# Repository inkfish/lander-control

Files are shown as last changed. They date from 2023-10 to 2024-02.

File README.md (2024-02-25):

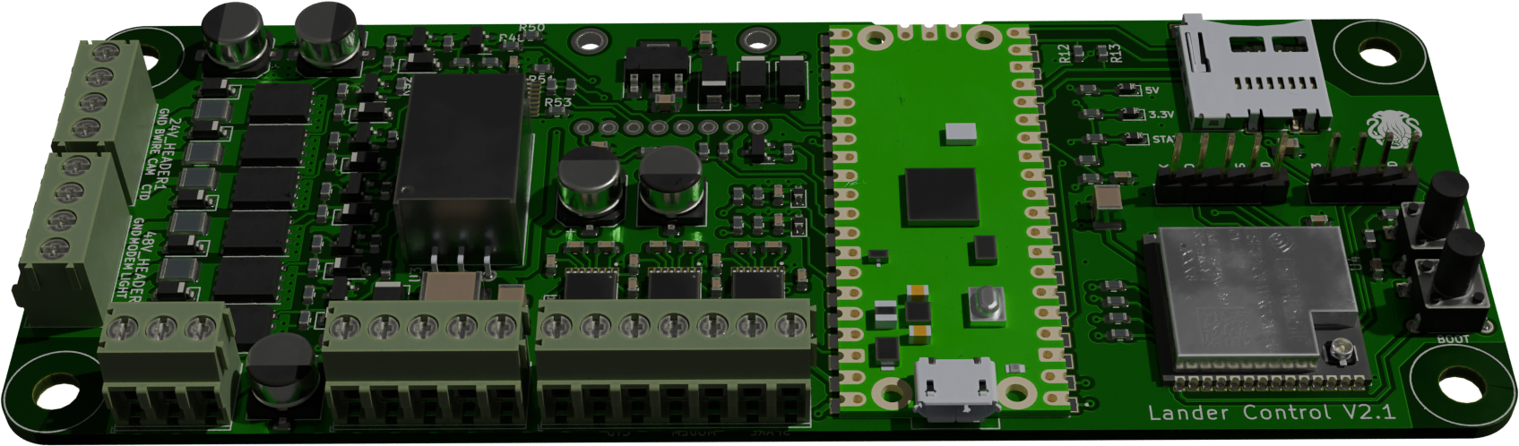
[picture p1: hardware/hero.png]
Hero image


# Lander Control Board for the Inkfish Hadal Exploration System

This repository contains firmware source code and hardware design files for the Lander Control Board used by the Inkfish Hadal Exploration System.

The Lander Control Board is responsible for switching power to the lander's peripherals, including a CTD, acoustic modem, camera, and lights. The board logs CTD data and responds to commands received via the acoustic modem.

The Lander Control Board is a motherboard for a [Raspberry Pi Pico][Pico]. A secondary microcontroller, an [Espressif ESP32-C6-WROOM-1U][ESP32], adds Wi-Fi capabilities. Timekeeping is assisted by an external GPS receiver along with an [Adafruit DS3231 Precision Real-Time Clock Breakout][RTC].

The firmware is written in [CircuitPython][] in order to be easily modifiable in the field and for compatibility with future microcontrollers. Data will be logged in the [MCAP][] file format.

[CircuitPython]: https://circuitpython.org/
[ESP32]: https://www.espressif.com/en/products/socs/esp32-c6
[MCAP]: https://mcap.dev/
[Pico]: https://www.raspberrypi.com/products/raspberry-pi-pico/
[RTC]: https://www.adafruit.com/product/3013

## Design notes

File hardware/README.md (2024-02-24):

# Hardware Design for Lander Control Board

This directory contains [KiCad][] schematic and PCB files for the Lander Control Board.

Designed by [Boston Precision Motion][] for Inkfish.

[Boston Precision Motion]: https://bostonprecisionmotion.com/
[KiCad]: https://www.kicad.org

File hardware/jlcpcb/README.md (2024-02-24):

This directory contains files to assist in preparing the design files for production at [JLCPCB][] using the [JLCPCB Tools][kicad-jlcpcb-tools] plugin.

Production files (Gerber files, BOMs, etc.) will also be attached on the project's Releases pages.

[JLCPCB]: https://jlcpcb.com/
[kicad-jlcpcb-tools]: https://github.com/Bouni/kicad-jlcpcb-tools

## Loading the project database

The KiCad plugin stores a mapping of footprints to LCSC part numbers (the same part numbers used by JLCPCB) in a SQLite database. The database can be created from the `project.db.sql` file, and vice versa:

    $ rm -f project.db && sqlite3 project.db < project.db.sql
    $ sqlite3 project.db .dump > project.db.sql

## Loading the rotations

JLCPCB parts usually need to be rotated by some amount to get the correct placement during assembly. The mapping of footprint to rotation is provided in `rotations.csv`.

To import, open the KiCad plugin's interface (Tools > External Plugins > JLCPCB Tools), click "Rotations" on the toolbar, then click the "Import" button and select the `rotations.csv` file.

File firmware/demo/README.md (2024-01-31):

This directory contains simple scripts for testing functionality of individual board components.

To load a script, attach the Raspberry Pi Pico to a PC using a USB cable. The volume "CIRCUITPY" should appear. Copy the demo script to this drive.

> [!IMPORTANT]  
> An issue with the userspace FAT driver on macOS prevents copying to the CIRCUITPY volume ([issue #8449](https://github.com/adafruit/circuitpython/issues/8449)). The script `./utils/remount-circuitpy.sh` works around this bug.

Open a serial connection to the Pico and press Ctrl-C to break into the REPL. Enter `import scriptname` (omitting the `.py` extension) to run the code.

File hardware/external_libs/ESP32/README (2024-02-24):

A 3D model of this component can be obtained from

https://grabcad.com/library/esp32-c6-wroom-1u-1

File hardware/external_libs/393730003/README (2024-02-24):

Please obtain this library from Ultra Librarian:

https://app.ultralibrarian.com/details/8e2498f5-ea90-11eb-9033-0a34d6323d74/Molex-Connector-Corporation/393730003

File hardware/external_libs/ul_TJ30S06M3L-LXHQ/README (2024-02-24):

Please obtain this library from Ultra Librarian:

https://app.ultralibrarian.com/details/ae27674b-4302-11eb-9033-0a34d6323d74/Toshiba-Electronic-Devices-Storage-Corp-/TJ30S06M3L-LXHQ

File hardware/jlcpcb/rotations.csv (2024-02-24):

Footprint pattern | Correction
^C_0603_1608Metric$ | 0
^C_0805_2012Metric$ | 0
^C_1210_3225Metric$ | 0
^C_2220_5650Metric$ | 0
^CP_Elec_6\.3x4\.9$ | 0
^D_0603_1608Metric$ | 0
^D_SMA$ | 0
^D_SOD-123$ | 0
^GCT_MEM2051-00-195-00-A$ | 90
^MODULE_SC0915$ | 270
^PinHeader_1x04_P2\.54mm_Vertical$ | 90
^PinHeader_1x05_P2\.54mm_Vertical$ | 90
^PowerPAK_SO-8_Single$ | 0
^R_0603_1608Metric$ | 0
^R_1206_3216Metric$ | 0
^R_1210_3225Metric$ | 0
^SI7489DP-T1-E3$ | 270
^SOP65P640X110-16N$ | 270
^SOP65P640X120-16N$ | 270
^SOT-223-3_TabPin2$ | 180
^SOT-23$ | 180

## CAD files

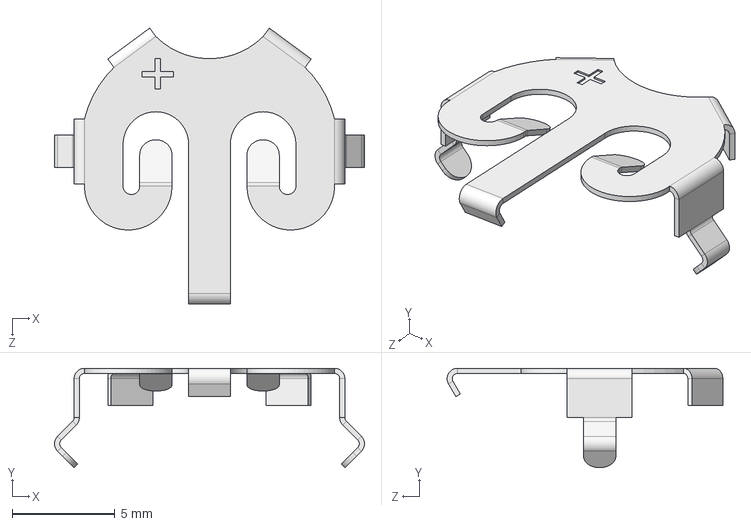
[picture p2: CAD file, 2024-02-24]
hardware/external_libs/CellHolder/2895.step
15.1 x 4.85 x 13.5 mm

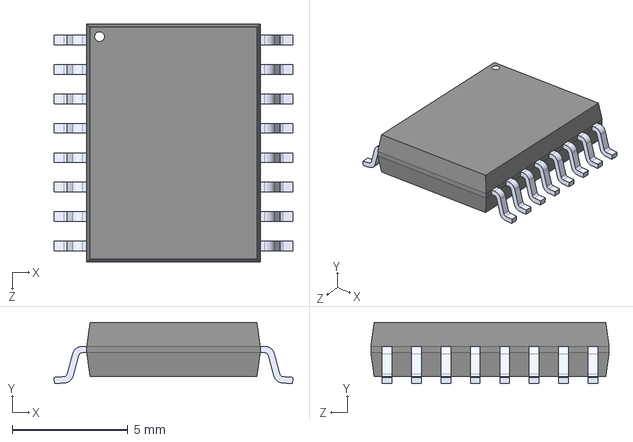
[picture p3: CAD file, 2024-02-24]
hardware/external_libs/DS3231S/DS3231S.step
10.3 x 2.65 x 10.3 mm

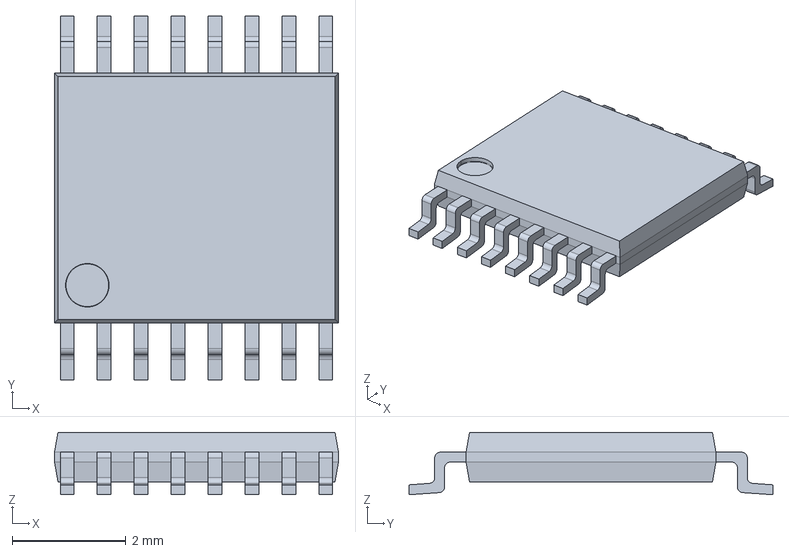
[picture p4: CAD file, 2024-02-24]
hardware/external_libs/GPIOEXPANDER/PCA9500PW_118.step
5.00 x 6.41 x 1.10 mm

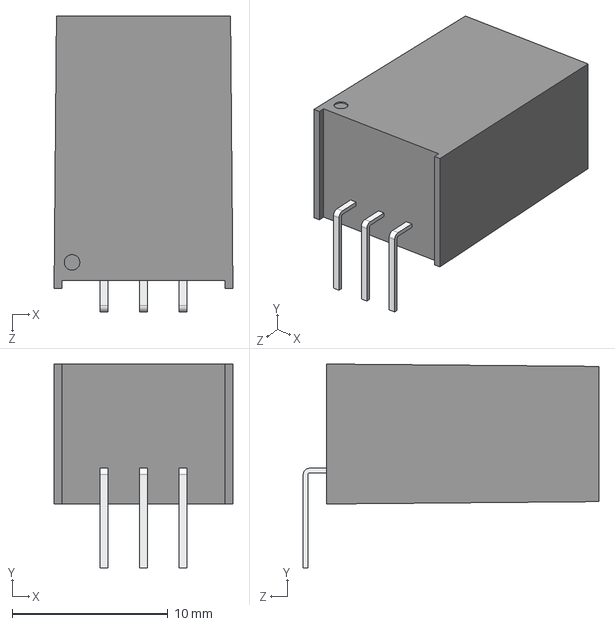
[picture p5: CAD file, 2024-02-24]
hardware/external_libs/P7805-500R/P7805-500R.step
11.5 x 13.1 x 19.0 mm

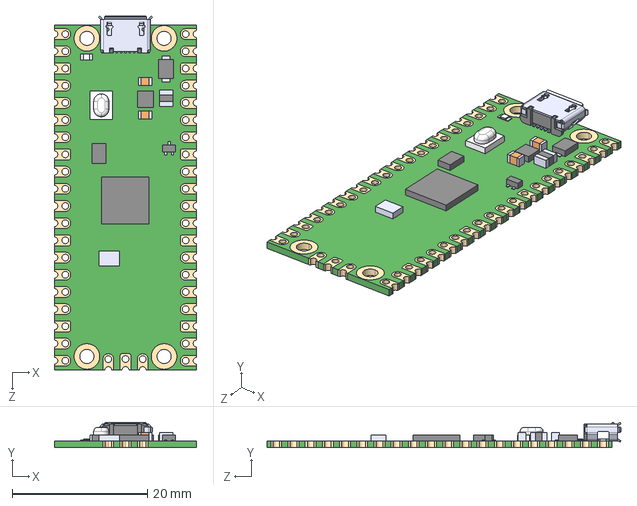
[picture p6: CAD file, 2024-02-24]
hardware/external_libs/PICO/SC0915.step
21.0 x 3.73 x 52.3 mm

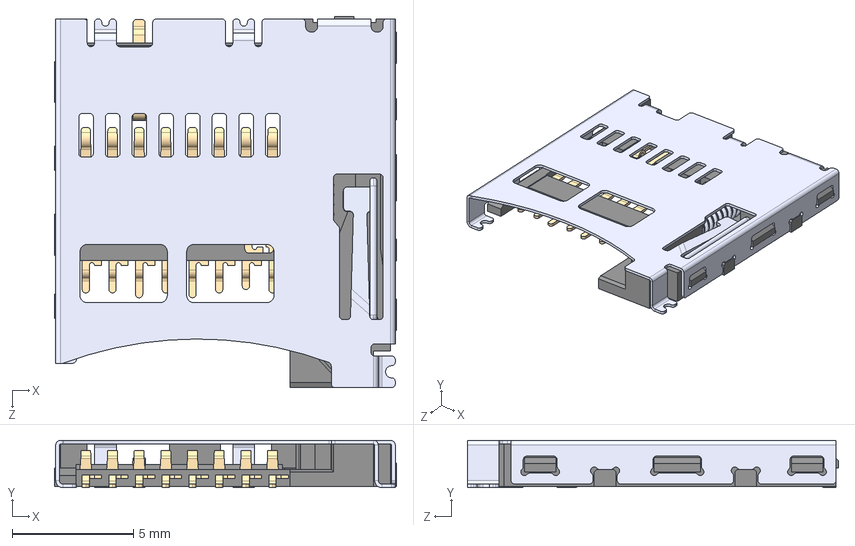
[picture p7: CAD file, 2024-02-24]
hardware/external_libs/sdcard/MEM2051-00-195-00-A.step
14.1 x 1.95 x 15.3 mm

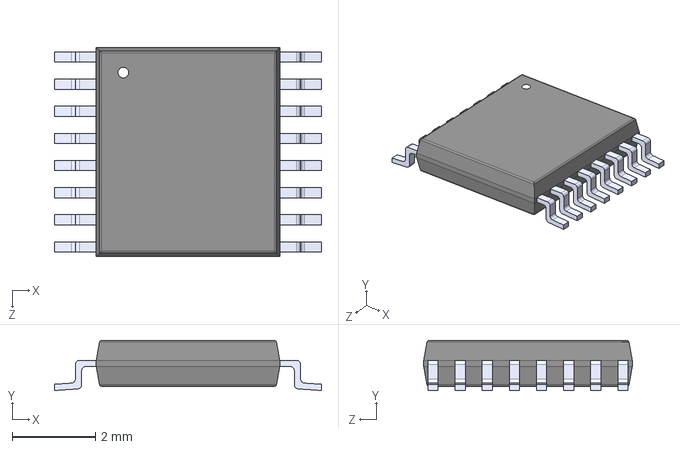
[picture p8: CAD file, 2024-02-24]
hardware/external_libs/SN65C3221EPWR/SN65C3221EPWR.step
6.40 x 1.20 x 5.00 mm

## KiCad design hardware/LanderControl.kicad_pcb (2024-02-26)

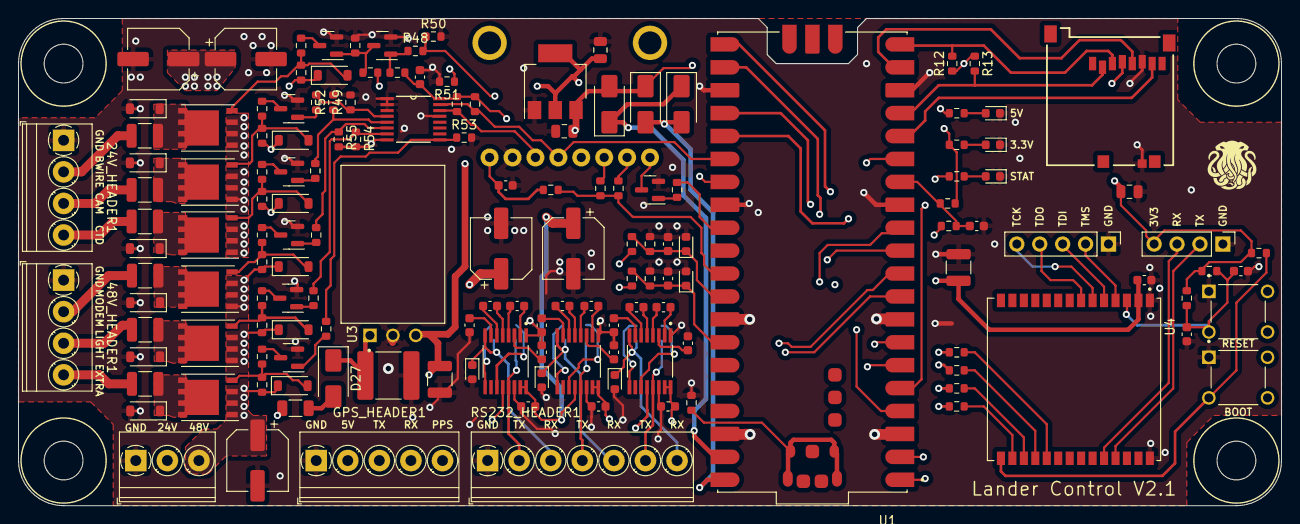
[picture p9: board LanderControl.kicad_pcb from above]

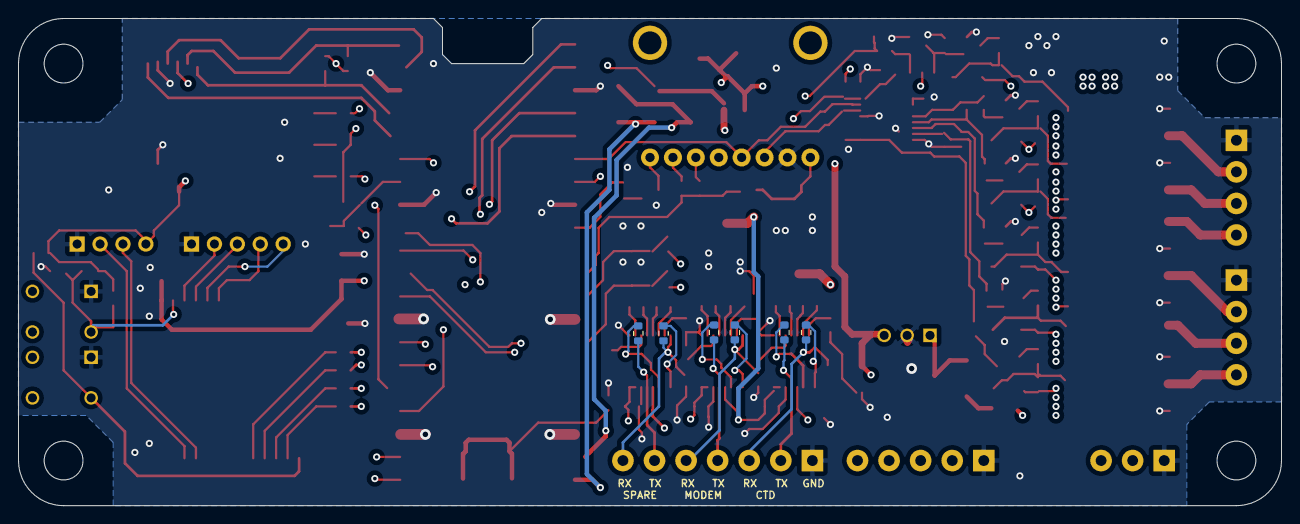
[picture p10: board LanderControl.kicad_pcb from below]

Board: 4 copper layers, 140.0 x 54.0 mm, 157 parts (6 on the bottom side), 115 nets.

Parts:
24V_HEADER1, 48V_HEADER1: Conn_01x04; TerminalBlock_Phoenix_PT-1,5-4-3.5-H_1x04_P3.50mm_Horizontal
C1, C2, C30: 1nF; C_0603_1608Metric
C3, C5, C12, C13, C14, C15, C16, C17, C18, C19, C20, C21, C22, C23, C24, C25, C26: 100nF; C_0603_1608Metric
C4, C11, C27: 1uF; C_0603_1608Metric
C6, C8: 22uF; C_1210_3225Metric
C7: 10uF; C_2220_5650Metric
C9, C10: 1uF; C_0805_2012Metric
C28, C29, C35, C37: >25V>25uF; CP_Elec_6.3x4.9
C31: 4.7uF; C_0805_2012Metric
C36: >50V>25uF; CP_Elec_6.3x4.9
D1, D2, D8, D10, D12: D_Zener; D_0603_1608Metric
D3, D25, D26, D27: B120-E3; D_SMA
D4, D5, D6: LED; D_0603_1608Metric
D13, D14, D17, D18, D21, D22: D_Zener; D_SOD-123
D15, D16, D19, D23, D24: 1N4148W; D_SOD-123
D20: SS210LW; D_SOD-123
DNP1, DNP2, DNP3, DNP4, DNP5, DNP6: 0; R_0603_1608Metric
DNP_R1: 0; R_0603_1608Metric
GPS_HEADER1: Conn_01x05; TerminalBlock_Phoenix_PT-1,5-5-3.5-H_1x05_P3.50mm_Horizontal
J2: Conn_01x04; PinHeader_1x04_P2.54mm_Vertical
J3: Conn_01x05; PinHeader_1x05_P2.54mm_Vertical
J5: MEM2051-00-195-00-A; GCT_MEM2051-00-195-00-A
PWR_IN1: Conn_01x03; TerminalBlock_Phoenix_PT-1,5-3-3.5-H_1x03_P3.50mm_Horizontal
Q1, Q2, Q3, Q4, Q5, Q6, Q7, Q8: BC846; SOT-23
R1: 49.9k; R_0603_1608Metric
R2, R4: 4.99k; R_0603_1608Metric
R3, R34: 100k; R_0603_1608Metric
R5, R6, R7, R21, R48: 560; R_0603_1608Metric
R8, R9, R12, R13, R14, R20, R25, R26, R27, R28, R29, R30, R31, R32, R35, R36, R37, R38, R39, R40, R41, R42, R43, R44, R45, R46: 10k; R_0603_1608Metric
R10, R11, R15, R16, R22, R23, R24: 0; R_0603_1608Metric
R19: 2.2; R_1206_3216Metric
R33: 4.7k; R_0603_1608Metric
R47: 47; R_0603_1608Metric
R49, R50, R51, R52, R53, R54, R55: 1k; R_0603_1608Metric
RS232_HEADER1: Conn_01x07; TerminalBlock_Phoenix_PT-1,5-7-3.5-H_1x07_P3.50mm_Horizontal
S1, S2: TS02-66-100-BK-100-LCR-D; SW_TS02-66-100-BK-100-LCR-D
TH1, TH2, TH3, TH4, TH5, TH6: Thermistor_PTC; R_1210_3225Metric
U1: SC0915; MODULE_SC0915
U3: P7805-500R; CONV_P7805-500R
U4: ESP32-C6-WROOM-1U-N4; XCVR_ESP32-C6-WROOM-1U-N4
U5: DS3231_breakout
U6, U7, U8: SN65C3221EPWR; SOP65P640X120-16N
U9, U10, U11, U12, U13, U14: SI7489DP-T1-E3; PowerPAK_SO-8_Single
U15: TCA9534APWR; SOP65P640X110-16N
U16: AMS1117; SOT-223-3_TabPin2

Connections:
+3V3: C5.2, C6.2, C10.1, C11.1, C16.2, C21.2, C26.2, C27.1, C28.1, C31.1, J2.4, J5.4 (VDD), R6.1, R8.2, R9.2, R12.1, R13.1, R14.1, R20.1, R24.2, R31.2, R45.1, R46.1, U4.2 (3V3), U5.1 (3V3), U6.12 (FORCEON), U6.15 (VCC), U6.16 (~FORCEOFF), U7.12 (FORCEON), U7.15 (VCC), U7.16 (~FORCEOFF), U8.12 (FORCEON), U8.15 (VCC), U8.16 (~FORCEOFF), U15.16 (VDD), U16.2 (VO)
+5V: C8.2, C9.1, D3.2 (A), D25.1 (K), GPS_HEADER1.2, R5.1, U3.3 (+VO), U16.3 (VI)
+24V: C35.1, C37.1, D14.1 (K), D18.1 (K), D22.1 (K), PWR_IN1.2, R1.1, R19.2, R29.2, R37.2, R43.2, U10.1 (S), U10.2 (S), U10.3 (S), U12.1 (S), U12.2 (S), U12.3 (S), U14.1 (S), U14.2 (S), U14.3 (S)
+48V: C36.1, D13.1 (K), D17.1 (K), D21.1 (K), PWR_IN1.3, R3.1, R27.2, R35.2, R41.2, U9.1 (S), U9.2 (S), U9.3 (S), U11.1 (S), U11.2 (S), U11.3 (S), U13.1 (S), U13.2 (S), U13.3 (S)
/CAMERA_POWER: R26.2, R49.1, U15.4 (IO0)
/CTD_POWER: R40.2, R52.1, U15.5 (IO1)
/ESP32/BOOT: R46.2, S2.3, U4.15 (IO9)
/ESP32/EN: C3.1, C4.2, R14.2, R45.2, S1.3, U4.3 (EN)
/ESP32/ESP_RX: J2.3, U4.24 (RXD0/GPIO17)
/ESP32/ESP_TX: J2.2, U4.25 (TXD0/GPIO16)
/ESP32/TCK: J3.5, U4.6 (IO6)
/ESP32/TDI: J3.3, U4.5 (IO5)
/ESP32/TDO: J3.4, U4.7 (IO7)
/ESP32/TMS: J3.2, U4.4 (IO4)
/LIGHT_POWER: R32.2, R54.1, U15.7 (IO3)
/MODEM_POWER: R25.2, R55.1, U15.6 (IO2)
/SPARE_48V_POWER: R39.2, R53.1, U15.9 (IO4)
/connectors/CTD_RX_232: D8.1 (K), DNP2.1, RS232_HEADER1.3, U6.8 (RIN)
/connectors/CTD_TX_232: DNP1.2, RS232_HEADER1.2, U6.13 (DOUT)
/connectors/MODEM_RX_232: D10.1 (K), DNP4.1, RS232_HEADER1.5, U7.8 (RIN)
/connectors/MODEM_TX_232: DNP3.2, RS232_HEADER1.4, U7.13 (DOUT)
/connectors/SPARE_RX_232: D12.1 (K), DNP6.1, RS232_HEADER1.7, U8.8 (RIN)
/connectors/SPARE_TX_232: DNP5.2, RS232_HEADER1.6, U8.13 (DOUT)
BURN_WIRE_PWR_OUT: 24V_HEADER1.2, TH4.1
CAMERA_PWR_OUT: 24V_HEADER1.3, TH2.1
EXTRA_24V_PWR_OUT: 24V_HEADER1.4, TH6.1
EXTRA_48V_PWR_OUT: 48V_HEADER1.4, TH5.1
GND: 24V_HEADER1.1, 48V_HEADER1.1, C1.2, C2.2, C3.2, C4.1, C5.1, C6.1, C7.2, C8.1, C9.2, C10.2, C11.2, C14.1, C15.1, C16.1, C19.1, C20.1, C21.1, C24.1, C25.1, C26.1, C27.2, C28.2, C29.2, C30.2, C31.2, C35.2, C36.2, C37.2, D1.2 (A), D2.2 (A), D4.1 (K), D5.1 (K), D6.1 (K), D8.2 (A), D10.2 (A), D12.2 (A), D15.2 (A), D16.2 (A), D19.2 (A), D20.2 (A), D23.2 (A), D24.2 (A), DNP_R1.2, GPS_HEADER1.1, J2.1, J3.1, J5.6 (VSS), J5.9 (DETECH), PWR_IN1.1, Q1.2 (E), Q2.2 (E), Q3.2 (E), Q4.2 (E), Q5.2 (E), Q6.2 (E), Q7.2 (E), Q8.2 (E), R2.2, R4.2, R34.2, R49.2, R50.2, R51.2, R52.2, R53.2, R54.2, R55.2, RS232_HEADER1.1, S1.1, S2.1, U1.3 (GND), U1.8 (GND), U1.13 (GND), U1.18 (GND), U1.23 (GND), U1.28 (GND), U1.33 (AGND), U1.38 (GND), U1.D2 (GND), U3.2 (GND), U4.1 (GND), U4.28 (GND__1), U5.2 (GND), U6.1 (~EN), U6.14 (GND), U7.1 (~EN), U7.14 (GND), U8.1 (~EN), U8.14 (GND), U15.1 (A0), U15.2 (A1), U15.3 (A2), U15.8 (VSS), U15.13 (~WC), U16.1 (ADJ)
GP0: DNP1.1, U1.1 (GP0), U6.11 (DIN)
GP1: DNP2.2, U1.2 (GP1), U6.9 (ROUT)
GP2: R48.2, R50.1, U1.4 (GP2)
GP3: R7.1, U1.5 (GP3)
GP4: DNP3.1, U1.6 (GP4), U7.11 (DIN)
GP5: DNP4.2, U1.7 (GP5), U7.9 (ROUT)
GP6: DNP5.1, U1.9 (GP6), U8.11 (DIN)
GP7: DNP6.2, U1.10 (GP7), U8.9 (ROUT)
GP8: GPS_HEADER1.3, U1.11 (GP8)
GP9: GPS_HEADER1.4, U1.12 (GP9)
GP10: C30.1, R24.1, R47.2, U1.14 (GP10)
GP11: R33.2, R51.1, U1.15 (GP11)
GP12: J5.7 (DATA0), U1.16 (GP12)
GP13: J5.2 (DATA3/CD), R13.2, U1.17 (GP13)
GP14: J5.5 (CLK), U1.19 (GP14)
GP15: J5.3 (CMD), R12.2, U1.20 (GP15)
GP16: R10.1, U1.21 (GP16)
GP17: R11.1, U1.22 (GP17)
GP18: R16.1, U1.24 (GP18)
GP19: R15.1, U1.25 (GP19)
GP20: R8.1, U1.26 (GP20), U5.4 (SDA), U15.15 (SDA)
GP21: R9.1, U1.27 (GP21), U5.3 (SCL), U15.14 (SCL)
GP22: R21.1, U1.29 (GP22)
GP26: R20.2, R22.1, R23.1, U1.31 (GP26)
GP27: C1.1, D1.1 (K), R1.2, R2.1, U1.32 (GP27)
GP28: C2.1, D2.1 (K), R3.2, R4.1, U1.34 (GP28)
LIGHT_PWR_OUT: 48V_HEADER1.3, TH3.1
MODEM_PWR_OUT: 48V_HEADER1.2, TH1.1
unnamed: D4.2 (A), R5.2
unnamed: D5.2 (A), R6.2
unnamed: D6.2 (A), R7.2
unnamed: D13.2 (A), R27.1, R28.2, U9.4 (G)
unnamed: D14.2 (A), R29.1, R30.2, U10.4 (G)
unnamed: D15.1 (K), TH1.2, U9.5 (D)
unnamed: D16.1 (K), TH2.2, U10.5 (D)
unnamed: D17.2 (A), R35.1, R36.2, U11.4 (G)
unnamed: D18.2 (A), R37.1, R38.2, U12.4 (G)
unnamed: D19.1 (K), TH3.2, U11.5 (D)
unnamed: D20.1 (K), TH4.2, U12.5 (D)
unnamed: D21.2 (A), R41.1, R42.2, U13.4 (G)
unnamed: D22.2 (A), R43.1, R44.2, U14.4 (G)
unnamed: D23.1 (K), TH5.2, U13.5 (D)
unnamed: D24.1 (K), TH6.2, U14.5 (D)
unnamed: D3.1 (K), D26.1 (K), U1.39 (VSYS)
unnamed: D27.2 (A), R19.1
unnamed: C7.1, C29.1, D27.1 (K), U3.1 (+VIN)
unnamed: DNP_R1.1, U1.A (USB_SHIELD), U1.B (USB_SHIELD), U1.C (USB_SHIELD), U1.D (USB_SHIELD)
unnamed: GPS_HEADER1.5, R47.1
unnamed: Q1.1 (B), R21.2
unnamed: Q1.3 (C), U5.8 (!RTC_RST)
unnamed: Q2.1 (B), R25.1
unnamed: Q2.3 (C), R28.1
unnamed: Q3.1 (B), R26.1
unnamed: Q3.3 (C), R30.1
unnamed: Q4.1 (B), R31.1, R48.1
unnamed: Q4.3 (C), Q6.1 (B), R33.1, R34.1
unnamed: Q5.1 (B), R32.1
unnamed: Q5.3 (C), R36.1
unnamed: Q6.3 (C), R38.1
unnamed: Q7.1 (B), R39.1
unnamed: Q7.3 (C), R42.1
unnamed: Q8.1 (B), R40.1
unnamed: Q8.3 (C), R44.1
unnamed: R11.2, U4.16 (IO18)
unnamed: R16.2, U4.17 (IO19)
unnamed: R10.2, U4.18 (IO20)
unnamed: R15.2, U4.19 (IO21)
unnamed: R23.2, U5.6 (32KHZ)
unnamed: R22.2, U5.7 (SQW)
unnamed: C12.1, U6.2 (C1+)
unnamed: C12.2, U6.4 (C1-)
unnamed: C13.1, U6.5 (C2+)
unnamed: C13.2, U6.6 (C2-)
unnamed: C15.2, U6.3 (V+)
unnamed: C14.2, U6.7 (V-)
unnamed: C17.1, U7.2 (C1+)
unnamed: C17.2, U7.4 (C1-)
unnamed: C18.1, U7.5 (C2+)
unnamed: C18.2, U7.6 (C2-)
unnamed: C20.2, U7.3 (V+)
unnamed: C19.2, U7.7 (V-)
unnamed: C22.1, U8.2 (C1+)
unnamed: C22.2, U8.4 (C1-)
unnamed: C23.1, U8.5 (C2+)
unnamed: C23.2, U8.6 (C2-)
unnamed: C25.2, U8.3 (V+)
unnamed: C24.2, U8.7 (V-)

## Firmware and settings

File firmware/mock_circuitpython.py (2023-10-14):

import os
import sys
import unittest.mock

import pyfakefs.fake_filesystem_unittest


# Mock out CircuitPython modules
modules = [
    'alarm',
    'analogio',
    'board',
    'busio',
    'digitalio',
    'microcontroller',
    'sdcardio',
    'storage',
    'supervisor',
    'watchdog',
    'wifi',
]

for m in modules:
    sys.modules[m] = unittest.mock.NonCallableMagicMock()


# Mock out the filesystem.
#
# Caveat: This does not mock out storage.VfsFat.open(), etc. which will not
# cause the desired effect on the filesystem.
patcher = pyfakefs.fake_filesystem_unittest.Patcher()
patcher.setUp()

def fake_storage_mount(filesystem, mount_path: str,
                       readonly: bool = False) -> None:
    os.mkdir(mount_path)

sys.modules['storage'].mount = fake_storage_mount



# Example of reading a value from a mocked analog GPIO pin
def main():
    import math
    import time

    import analogio
    import board


    class MockSinusoidAnalogIn(unittest.mock.MagicMock):
        def __init__(self, pin):
            super().__init__()
            self.pin = pin

        @property
        def value(self):
            if self.pin is board.A0:
                return int(math.sin(time.monotonic()) * 32767) + 32768
            elif self.pin is board.A1:
                return int(math.cos(time.monotonic()) * 32767) + 32768
            return 0

        # Make children as regular MagicMock instances
        def _get_child_mock(self, /, **kwargs):
            return unittest.mock.MagicMock(**kwargs)


    with unittest.mock.patch('analogio.AnalogIn', new=MockSinusoidAnalogIn):
        adc0 = analogio.AnalogIn(board.A0)
        adc1 = analogio.AnalogIn(board.A1)

        while True:
            print(f'ADC0: {adc0.value:5}  ADC1: {adc1.value:5}')
            time.sleep(1)


if __name__ == '__main__':
    main()

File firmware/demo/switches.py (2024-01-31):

'''

'''

import board
import busio
import digitalio

import adafruit_pcf8574


gpio_expander = adafruit_pcf8574.PCF8574(
    busio.I2C(
        board.GP21,  # SCL
        board.GP20   # SDA
    )
)


# Power switches attached to the GPIO expander
pin_camera_power = gpio_expander.get_pin(0)
pin_spare_24v_power = gpio_expander.get_pin(1)
pin_modem_power = gpio_expander.get_pin(2)
pin_light_power = gpio_expander.get_pin(3)
pin_spare_48v_power = gpio_expander.get_pin(4)
pin_burn_wire = gpio_expander.get_pin(6)

for pin in [ pin_camera_power, pin_spare_24v_power, pin_modem_power,
             pin_light_power, pin_spare_48v_power, pin_burn_wire ]:
    pin.switch_to_output()


# Enable pin for burn wire
pin_burn_enable = digitalio.DigitalInOut(board.GP2)
pin_burn_enable.switch_to_output()


# Menu
print('''
Enter command: [number] [on|off]
    (24V)  1: Camera   2: Burn wire   3: Spare
    (48V)  4: Modem    5: Lights      6: Spare
           7: Burn wire enable
''')

while True:
    choice, _, state = input('> ').partition(' ')

    if state.lower() not in ('on', 'off', '1', '0', 'hi', 'high', 'lo', 'low'):
        print(f'Unknown state {state}, try again.')
        continue

    state = state.lower() in ('on', '1', 'hi', 'high')

    try:
        {
            '1': pin_camera_power,
            '2': pin_burn_wire,
            '3': pin_spare_24v_power,
            '4': pin_modem_power,
            '5': pin_light_power,
            '6': pin_spare_48v_power,
            '7': pin_burn_enable
        }[choice].value = state
    except KeyError:
        print(f'Unknown pin {choice}, try again.')
        continue

    print('Switched pin', choice, 'to', 'on' if state else 'off')

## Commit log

2023-10-14 Add CircuitPython demos
2023-10-14 Add means of mocking CircuitPython APIs on CPython
2023-10-14 Add an example of a mock analog GPIO pin
2023-10-27 Add demo for LED control. Closes #14.
2024-01-23 Change resistor values to match schematic
2024-01-31 Update demo script for switches
2024-02-24 Initial import
    [2895.step, DS3231S.step, ESP32-S2-SOLO-U-N4R2.step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]
2024-02-24 Update references from ESP32-S2 to ESP32-C6
    [ESP32-S2-SOLO-U-N4R2.step, ESP32.kicad_sch, LanderControl.kicad_pcb]
2024-02-24 Add JLCPCB part and rotation mapping info
    [LanderControl.kicad_pcb, rotations.csv]
2024-02-24 Clean up silkscreen labels
    [LanderControl.kicad_pcb]
2024-02-24 Add Inkfish logo to silkscreen
    [LanderControl.kicad_pcb]
2024-02-24 Clean up tracks and vias, refill zones
    [LanderControl.kicad_pcb]
2024-02-24 Remove diodes from voltage monitoring circuit
    [LanderControl.kicad_pcb, LanderControl.kicad_sch]
2024-02-24 Exclude Adafruit DS3231 breakout from JLCPCB BOM
    [LanderControl.kicad_pcb]
2024-02-24 Replace PCA9500 I/O expander with TCA9534
    [GPIO_expander.kicad_sch, LanderControl.kicad_pcb]
2024-02-24 Add missing 3D models
    [LanderControl.kicad_pcb]
2024-02-26 Remove unneeded ESP32 thermal pads
    [LanderControl.kicad_pcb]
2024-02-26 Refill zones
    [LanderControl.kicad_pcb]
